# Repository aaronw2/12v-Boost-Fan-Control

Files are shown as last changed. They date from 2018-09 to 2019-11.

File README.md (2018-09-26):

# 12v-Boost-Fan-Control
This is a small board designed to boost 3-8v (typically 5v) up to 12v. 
In addition, it contains a N-channel mosfet which can be used to turn
a device on or off or to perform PWM on something like a fan.

This board was designed to efficiently power 12v computer fans using as
small a footprint as possible.  While it's certainly possible to go
smaller, this uses 0603 and larger devices.

On the input side there is +5, ground and a FET control line.  To
enable the FET as a ground type device, pull the FET control line
to 3v or higher and connect the device between +12 and FET-.  Note
that when the fet is not activated that the FET- will not provide 
ground.

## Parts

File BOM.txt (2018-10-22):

Designator	Value		Footprint	Part Number
C1		6.8uF		0603
C2		0.1uF		0603
C3		22uF 16V	1210
C4		1uF		0603
C5		0.022uF		0603
C6		820pf		0603
C7		0.047uF		0603
D1		Shottky 40V 2A	SOD-123F	ON Semi SS24FL
L1		3.3uH		IHLP-1212	Vishay IHLP1212BZER3R3M11
Q1		Mosfet N-CH	SOT-23		Infineon BSS214NW
R1		86.6K		0603
R2		18.2K		0603
R3		1.69K		0603
R4		10K 1%		0603
R5		100K		0603
U1		TI TPS55340	QFN-16-1EP 3x3mm 0.5mm pitch therm via

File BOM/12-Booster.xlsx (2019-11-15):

C2 | 100nF | Capacitor_SMD:C_0603_1608Metric | 1 | Samsung | CL10B104KO8WPNC | Digikey | 1276-6582-1-ND
C4 | 1uF | Capacitor_SMD:C_0603_1608Metric | 1 | Samsung | CL10B105KP8NNNC | Digikey | 1276-1946-1-ND
C5 | 22nF | Capacitor_SMD:C_0603_1608Metric | 1 | Samsung | CL10B223KB8WPNC | Digikey | 1276-6534-1-ND
C7 | 47nF | Capacitor_SMD:C_0603_1608Metric | 1 | Samsung | CL10B473KO8WPNC | Digikey | 1276-6852-1-ND
C1 | 6.8uF | Capacitor_SMD:C_0603_1608Metric | 1 | TDK | C1608X5R1E685K080AC | Digikey | 445-14145-1-ND
C6 | 820pF | Capacitor_SMD:C_0603_1608Metric | 1 | Kemet | C0603C821J5RACTU | Digikey | 399-9127-1-ND
C3 | 22uF | Capacitor_SMD:C_1210_3225Metric | 1 | Samsung | CL32B226MOJNNNE | Digikey | 1276-3395-1-ND
D1 | D_Schottky | Diodes_SMD:D_SOD-123F | 1 | ON | SS24FL | Digikey | SS24FLCT-ND
U1 | TPS55340-Q1 | Housings_DFN_QFN:QFN-16-1EP_3x3mm_Pitch0.5mm_ThermalVias | 1 | TI | TPS55340RTER | Digikey | 296-37677-1-ND
L1 | 3.3uH | Inductor_SMD:L_Vishay_IHLP-1212 | 1 | Vishay Dale | IHLP1212BZER3R3M11 | Digikey | 541-2567-1-ND
Q1 | BSS214NW | Package_TO_SOT_SMD:SOT-323_SC-70 | 1 | Infineon | BSS214NWH6327XTSA1 | Digikey | BSS214NWH6327XTSA1CT-ND
J2 | Conn_01x03 | Pin_Headers:Pin_Header_Angled_1x03_Pitch2.54mm | 1 | - | - | - | -
J1 | Conn_01x04 | Pin_Headers:Pin_Header_Angled_1x04_Pitch2.54mm | 1 | - | - | - | -
R3 | 1.69k | Resistor_SMD:R_0603_1608Metric | 1 | Vishay | CRCW06031K69FKEA | Digikey | 541-1.69KHCT-ND
R5 | 100k | Resistor_SMD:R_0603_1608Metric | 1 | TE | CRG0603F100K | Digikey | A106046CT-ND
R4 | 10k | Resistor_SMD:R_0603_1608Metric | 1 | Vishay Dale | CRCW060310K0FKEC | Digikey | 541-2979-1-ND
R2 | 18.2k | Resistor_SMD:R_0603_1608Metric | 1 | Vishay Dale | CRCW060318K2FKEA | Digikey | 541-18.2KHCT-ND
R1 | 86.6k | Resistor_SMD:R_0603_1608Metric | 1 | Vishay Dale | CRCW060386K6FKEA | Digikey | 541-86.6KHCT-ND

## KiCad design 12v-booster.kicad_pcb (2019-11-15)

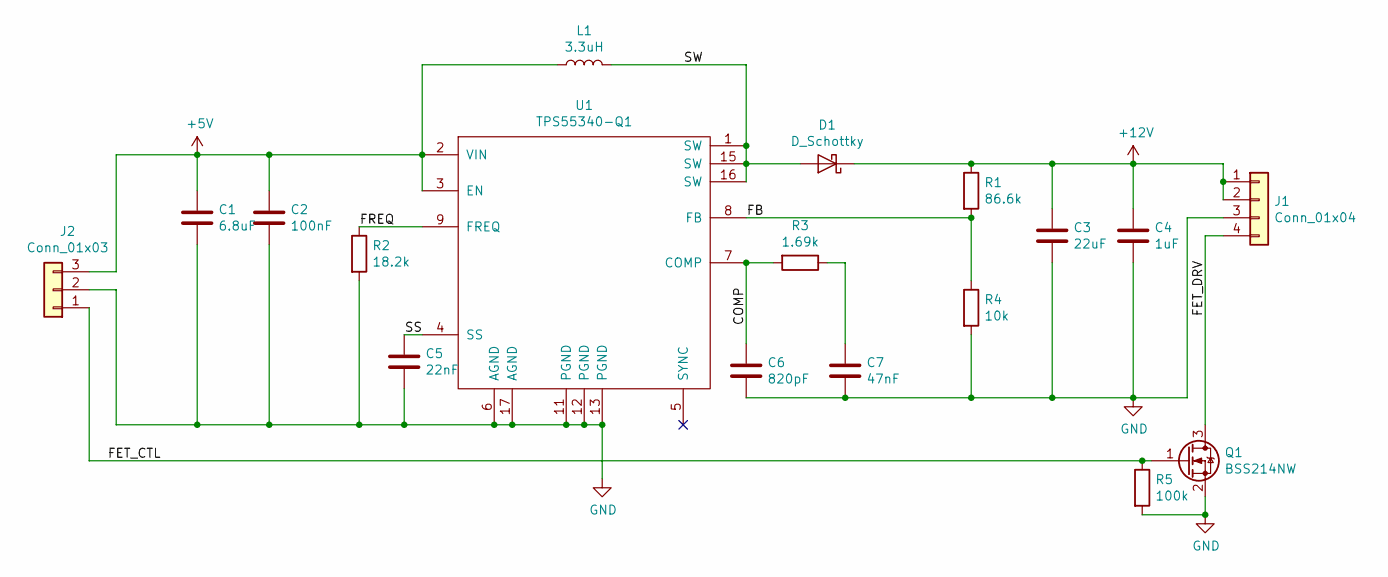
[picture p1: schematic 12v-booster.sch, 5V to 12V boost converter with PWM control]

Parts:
C1: 6.8uF; C_0603_1608Metric; MPN C1608X5R1E685K080AC
C2: 100nF; C_0603_1608Metric; MPN CL10B104KO8WPNC
C3: 22uF; C_1210_3225Metric; MPN CL32B226MOJNNNE
C4: 1uF; C_0603_1608Metric; MPN CL10B105KP8NNNC
C5: 22nF; C_0603_1608Metric; MPN CL10B223KB8WPNC
C6: 820pF; C_0603_1608Metric; MPN C0603C821J5RACTU
C7: 47nF; C_0603_1608Metric; MPN GRM188R61H474KA12D
D1: D_Schottky; D_SOD-123F; MPN SS24FL
J1: Conn_01x04; PinHeader_1x04_P2.54mm_Horizontal
J2: Conn_01x03; PinHeader_1x03_P2.54mm_Horizontal
L1: 3.3uH; L_Vishay_IHLP-1212; MPN IHLP1212BZER3R3M11
Q1: BSS214NW; SOT-323_SC-70; MPN BSS214NWH6327XTSA1
R1: 86.6k; R_0603_1608Metric; MPN CRCW060386K6FKEA
R2: 18.2k; R_0603_1608Metric; MPN CRCW060318K2FKEA
R3: 1.69k; R_0603_1608Metric; MPN CRCW06031K69FKEA
R4: 10k; R_0603_1608Metric; MPN CRCW060310K0FKEC
R5: 100k; R_0603_1608Metric; MPN CRG0603F100K
U1: TPS55340-Q1; QFN-16-1EP_3x3mm_P0.5mm_EP2.7x2.7mm_ThermalVias; MPN TPS55340RTER

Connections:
+5V: C1.1, C2.1, J2.3, L1.1, U1.2 (VIN), U1.3 (EN)
+12V: C3.1, C4.1, D1.1 (K), J1.1, J1.2, R1.1
/COMP: C6.1, R3.2, U1.7 (COMP)
/FB: R1.2, R4.1, U1.8 (FB)
/FET_CTL: J2.1, Q1.1 (G), R5.1
/FET_DRV: J1.4, Q1.3 (D)
/FREQ: R2.1, U1.9 (FREQ)
/SS: C5.1, U1.4 (SS)
/SW: D1.2 (A), L1.2, U1.1 (SW), U1.15 (SW), U1.16 (SW)
GND: C1.2, C2.2, C3.2, C4.2, C5.2, C6.2, C7.2, J1.3, J2.2, Q1.2 (S), R2.2, R4.2, R5.2, U1.6 (AGND), U1.11 (PGND), U1.12 (PGND), U1.13 (PGND), U1.17 (AGND)
unnamed: C7.1, R3.1

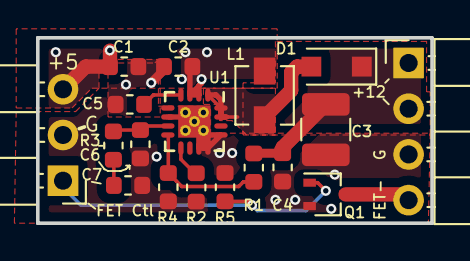
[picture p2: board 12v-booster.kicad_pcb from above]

Board: 2 copper layers, 21.9 x 10.3 mm, 18 parts (0 on the bottom side), 11 nets.

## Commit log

2018-09-26 Initial commit of revision 1.1.
    [12-Booster.csv, 12v-booster.kicad_pcb, 12v-booster.sch]
2018-09-26 Updated page size and description in schematic.
    [12v-booster.sch]
2018-10-11 Fixed solder mask clearance.
    [12v-booster.kicad_pcb]
2018-10-22 - Changed one ground to be +12V for 2 12V output pins - Cleaned up silkscreen
2018-10-22 Added BOM
2019-01-26 Fixed solder mask clearance
    [12-Booster.csv, 12v-booster.kicad_pcb, 12v-booster.sch]
2019-11-15 Revision 1.2.2
    [12-Booster.xlsx, 12v-booster.kicad_pcb]

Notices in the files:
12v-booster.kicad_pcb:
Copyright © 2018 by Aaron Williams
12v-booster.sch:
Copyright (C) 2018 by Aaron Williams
